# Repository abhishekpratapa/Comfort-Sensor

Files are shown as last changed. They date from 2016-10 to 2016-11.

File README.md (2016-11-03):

# Comfort-Sensor

This is a walk through of designing and manufacturing a microcontroller based project. The goal is to design a consumer product.

My new product is developed from this idea. It is capable of detecting the hygine levels in any environment. Bacteria, Mold, Dust, Hydrocarbon gases. Please email me if you have any questions or are interested in ordering such a product for your family. abhishekpratapa@gmail.com

## Introduction

I've been having a bunch of headaches lately and I didn't know what the cause of those headaches was. Secondarily, during these migraines, I would notice that my mouth felt extremely parched. Initially I had thought that the cause for these symptoms was that I wasn't drinking enough water. This, however, was not the case. I was drinking more than enough of my share of water and I was still feeling horrible. I needed to do something.

I finally arrived on the conclusion that the environment around me was partially causing these symptoms. I decided to build a sensor that told me the humidity and temperature readings in my environment; it would sort of be like a comfort indicator to determine whether these headaches were caused by my surroundings.

## Prototyping

### Planning the User Experience

User Experience is most important when designing a device like this one. What do we want the user to see? Based off of the limited number of components I had available to me I opted for an analog approach in displaying the temperature and the humidity. It would sort of be like a clock. PLEASE spend more time than I did on this. You need to nail this in order to retain customers or users. The User Experience is illustrated below.

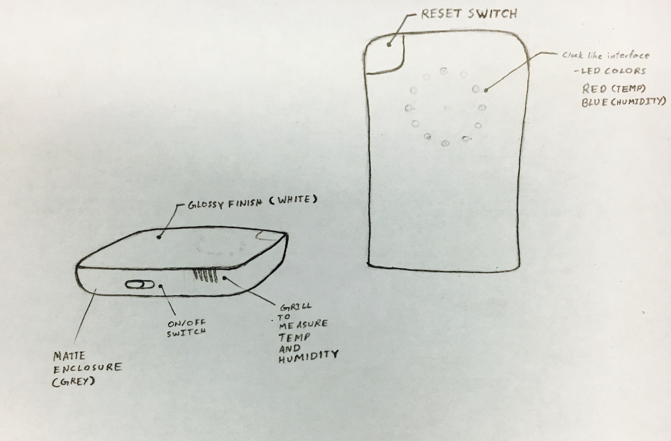
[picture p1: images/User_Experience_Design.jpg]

A Design Prototype

### List of Components

I began rummaging through my electronics and I managed to find a few components that I thought would be ideal to make such a device. They are listed below:

#### Components in the Prototype

- Neo Pixel Ring
- Teensy 3.1
- Battery Management Unit
- Switch
- DHT22 Humidity and Temperature Sensor
- LiPo Battery

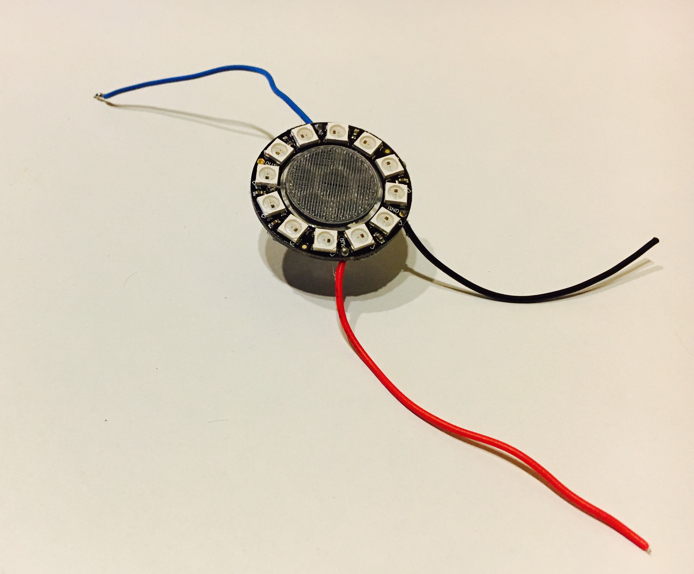
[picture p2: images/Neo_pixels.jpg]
Neo Pixels

Neo Pixel Ring

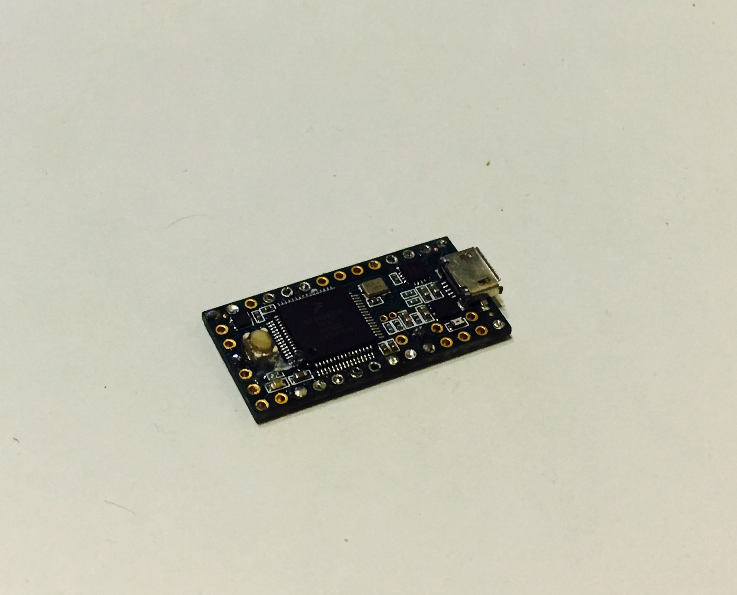
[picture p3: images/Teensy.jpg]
Teensy 3.1

Teensy 3.1

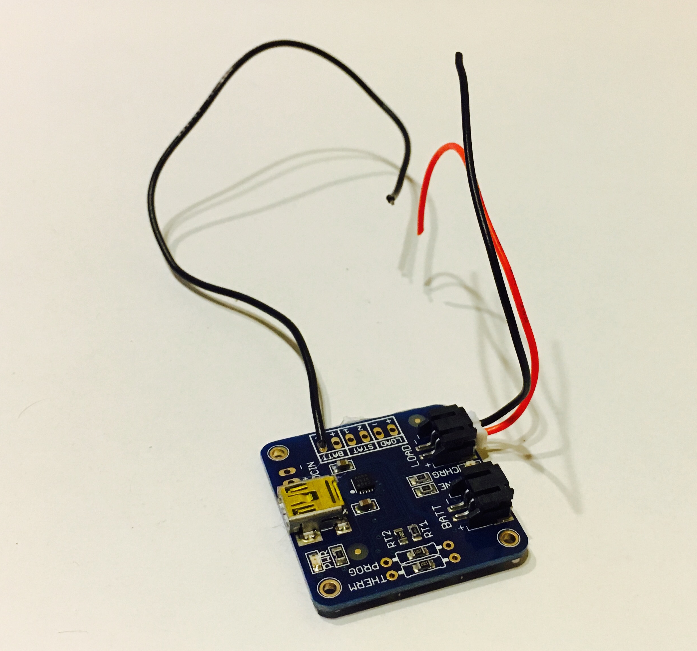
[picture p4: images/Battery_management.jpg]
Battery Management Unit

Battery Management Unit

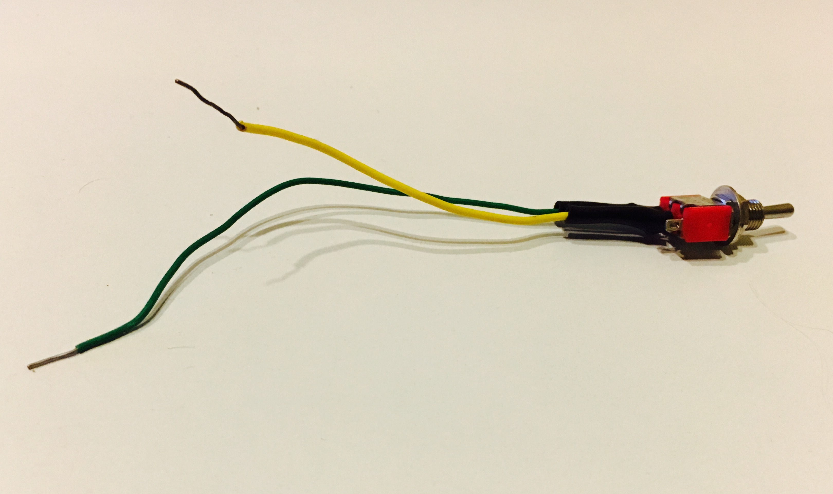
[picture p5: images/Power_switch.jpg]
Power Switch

Switch

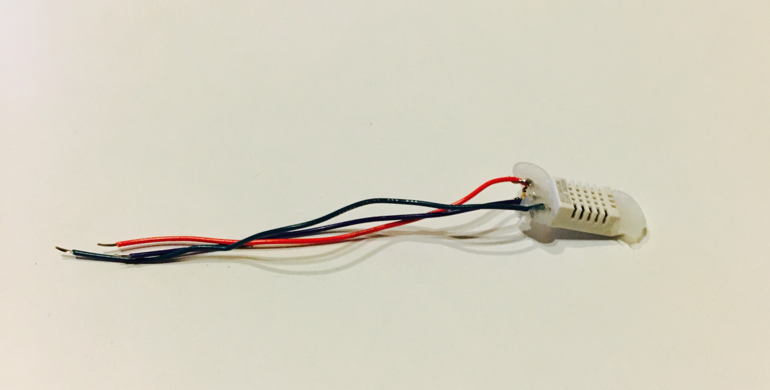
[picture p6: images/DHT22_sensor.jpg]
DHT22 Humidity and Temperature Sensor

DHT22 Humidity and Temperature Sensor

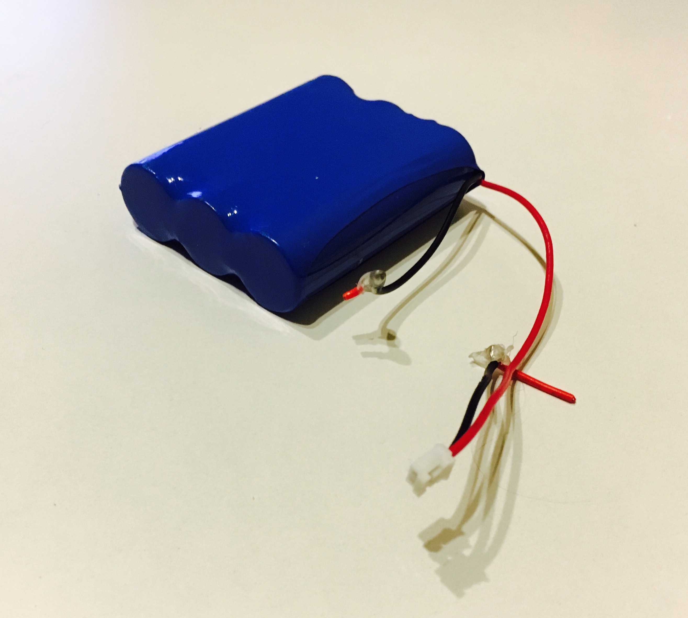
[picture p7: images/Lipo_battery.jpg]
Battery

LiPo Battery

#### Tools used to build the Prototype

- Flush Cutters
- Soldering Iron

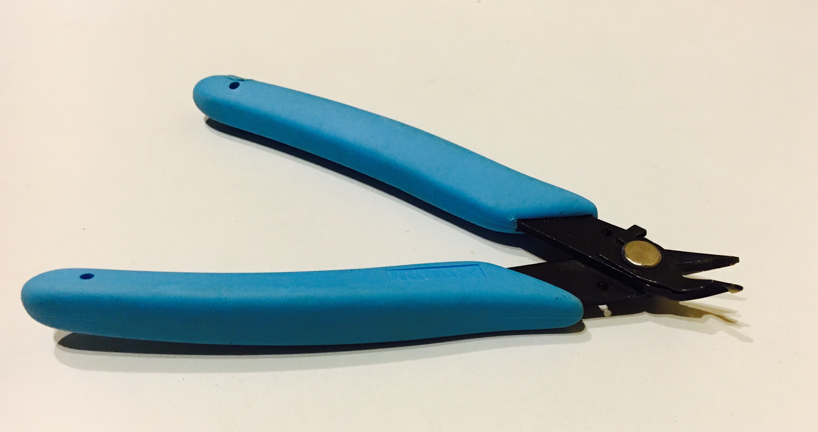
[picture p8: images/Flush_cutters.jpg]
Flush Cutters

Flush Cutters

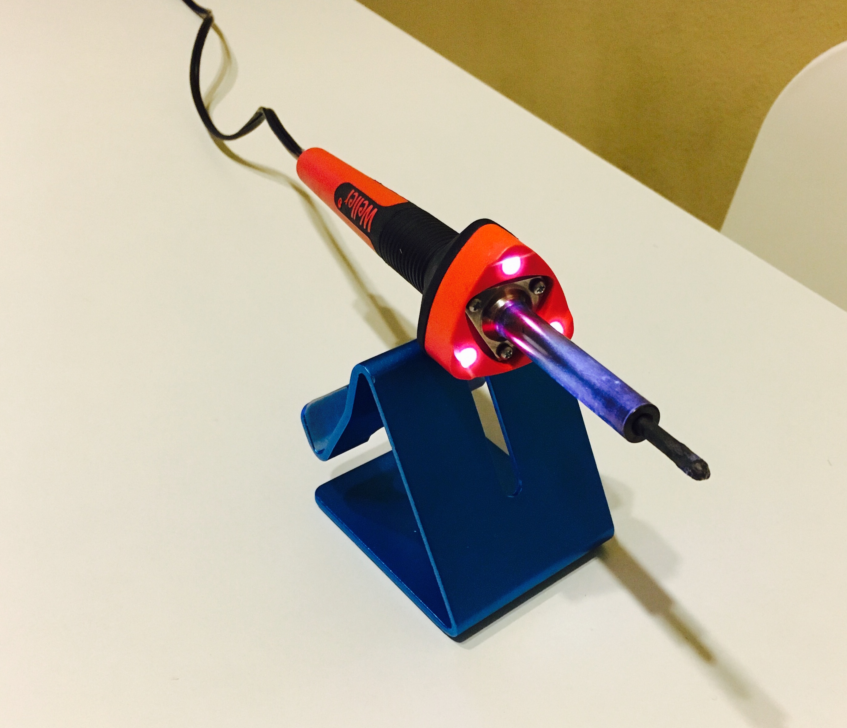
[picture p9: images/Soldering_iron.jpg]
Soldering Iron

Soldering Iron

### Planing the wiring Diagram

Below is a figure of the wiring diagram I created. It is fairly simple.

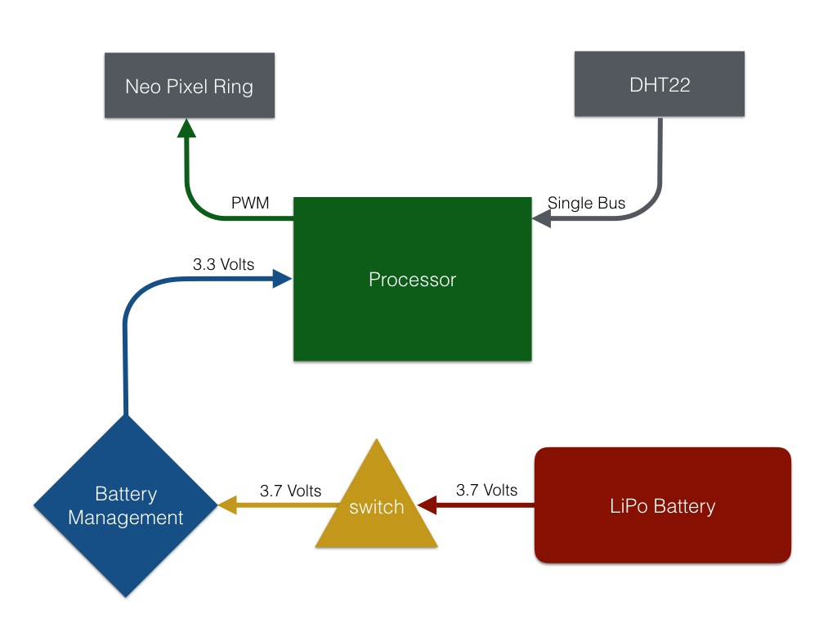
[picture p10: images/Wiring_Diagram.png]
Wiring Diagram

Wiring Diagram

### Wiring up the Prototype

I ended up wiring the device up before I tested it, I had run out of breadboards, and generally this is a horrible idea; however, this was not my first rodeo. I felt confident that I knew what I was doing. Everything worked out without any hiccups.

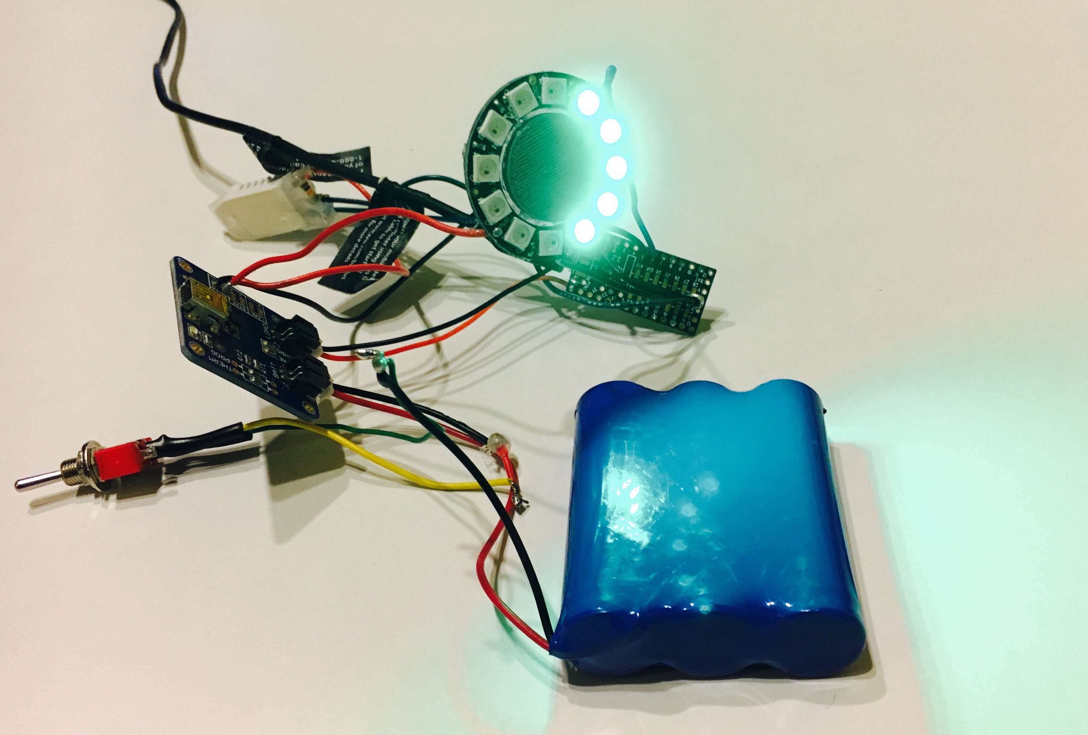
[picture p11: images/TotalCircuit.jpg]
Prototype Switch

Prototype Circuit

### Writing the software

The code design is shown below in the diagram.

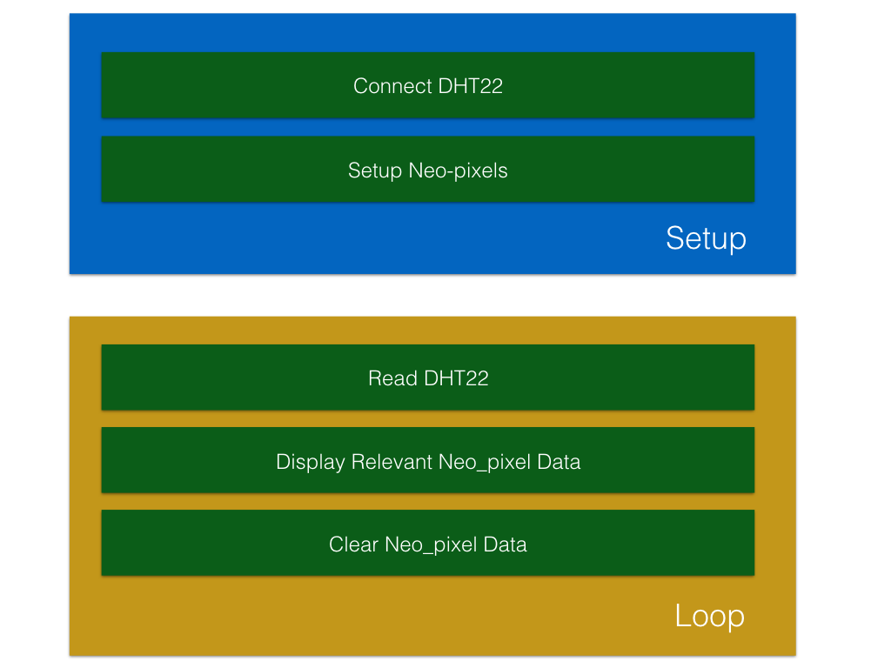
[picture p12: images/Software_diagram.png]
Method Break Down


### Method Break Down

Translating the design to code was a fairly straight forward process. Keeping things simple in Embedded systems design means that space on the micro controller is preserved and that everything is running efficiently. 

#### Setup Method
```
/*
 * Method:  setup
 * 
 * Action:  This method is the setup loop of the program, it sets up the
 *          DHT22 and the Neopixel objects
 * 
 * params:  [None]
 *          
 * return:  void
 * 
 */
```

#### Loop Method

```
/*
 * Method:  loop
 * 
 * Action:  This method is the main loop of the program, it structurally 
 *          calls the other methods to make the program cohesive
 * 
 * params:  [None]
 *          
 * return:  void
 * 
 */
```

#### Display_correct Method

```
/*
 * Method:  display_correct
 * 
 * Action:  This method takes in two parameters, displays the correct 
 *          number of Neo_pixels and the correct color for those pixels
 * 
 * params:  value       Integer value to be displayed in the neo_pixels
 *          sent_color: Enum type color, determines the color to be displayed 
 *                      on the neo_pixels
 *          
 * return:  void
 * 
 */
```

#### Clear_previous Method

```
/*
 * Method:  clear_previous
 * 
 * Action:  This method clears the Neo_pixels and sets the values of all the Neo_pixels to zero
 * 
 * params:  [None]
 * 
 * return:  void
 * 
 */
```

#### Read_sensors Method

```
/*
 * Method:  read_sensors
 * 
 * Action:  This method reads the DHT22 and places the proper data in an int pointer array
 * 
 * params:  *data_retrieved:  This is an Integer array pointer that stores the ones, and tens 
 *                            decimal places for the temperature and the humidity values.
 *                            The first two indexes are the humidity reading and the second two 
 *                            indexes are the temperature reading in [tens, ones] format.
 * 
 * return:  void
 * 
 */
```

### Finalizing 

Here is a video of the prototype of the device

[IMAGE ALT TEXT]
(http://www.youtube.com/watch?v=CA7ydEnhpj4 "Prototype Video")

## PCB Design

Here is the Schematic Design for the project. (Click on it to go to the PDF of the schematic)

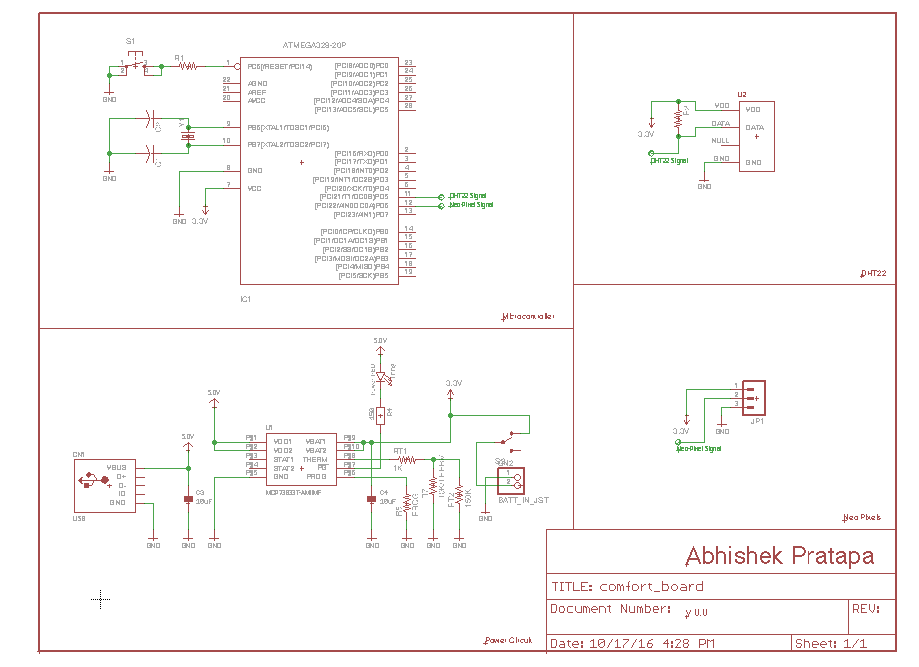
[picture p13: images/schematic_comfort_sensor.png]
IMAGE ALT TEXT
[]
(https://github.com/abhishekpratapa/Comfort-Sensor/blob/master/Comfort_Sensor_PCB/comfort_board.pdf "PDF Schematic")

Here is the PCB design for the project.

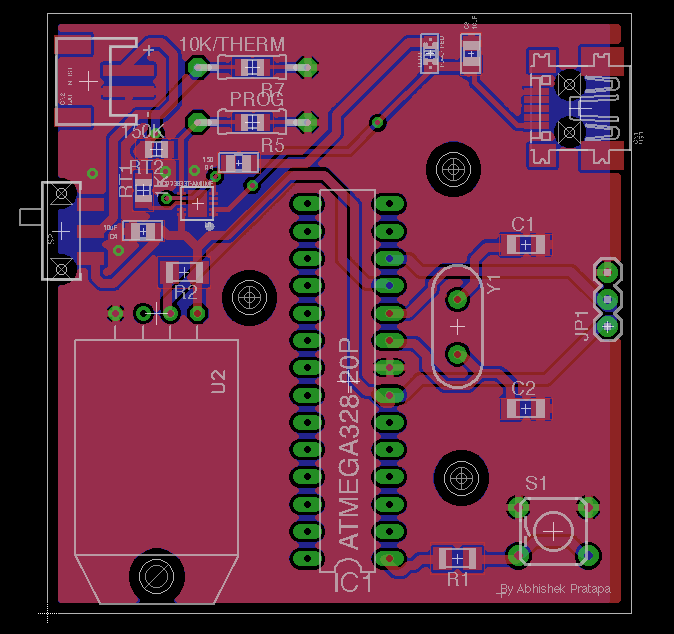
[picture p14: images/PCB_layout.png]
PCB Layout


Please take a look at the eagle CAD and schematic designs in: https://github.com/abhishekpratapa/Comfort-Sensor/tree/master/Comfort_Sensor_PCB

Here is a rendering of the Circuit in Solidworks
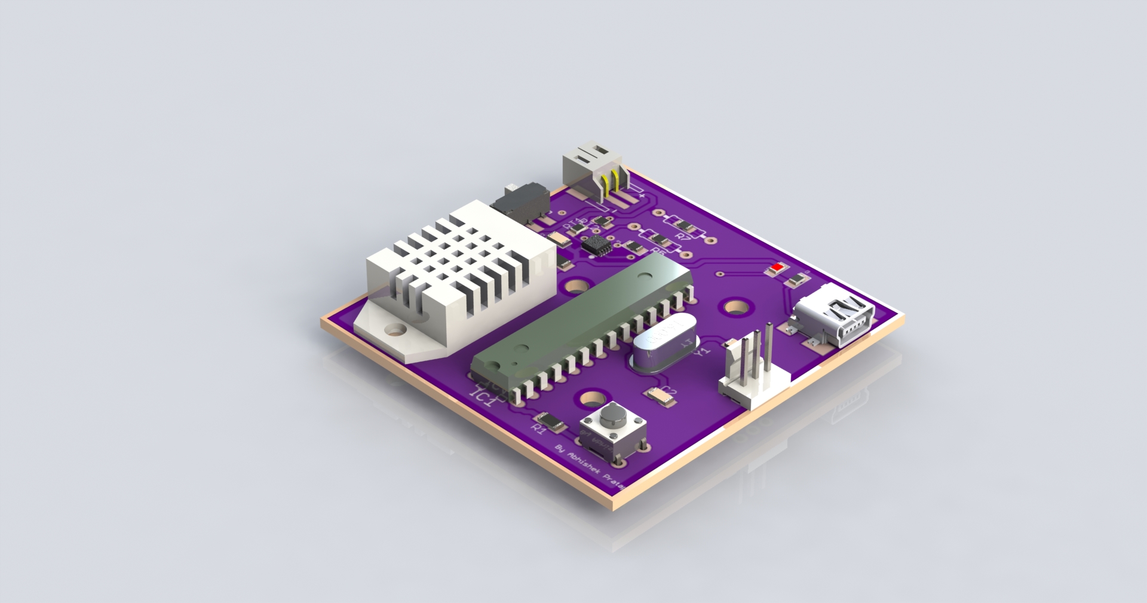
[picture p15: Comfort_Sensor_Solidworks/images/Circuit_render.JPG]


## Financing

### Low Volume

#### Components

| Name of Component | Quantity | Supplier | Price | Shipping | URL |
| :--- | :---: | :---: | :---: | :---: | :--- |
| ATMega328  | 1 | Mouser | $3.70 | $4.70 | http://www.mouser.com/ProductDetail/Atmel/ATMEGA328P-PU/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 |
| Crystal 16MHz | 1 | Mouser | $0.36 | $-.--  | http://www.mouser.com/ProductDetail/CTS/ATS16B-E/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 |
| DHT22  | 1 | Ebay | $3.70 | $-.-- | http://www.ebay.com/itm/New-DHT22-AM2302-Digital-Temperature-Humidity-Sensor-Replace-SHT11-SHT15-Arduino/162147611172 |
| Mini-Pushbutton | 1 | Sparkfun | $0.35 | $2.35  | https://www.sparkfun.com/products/97 |
| Neo-Pixel Ring | 1 | Adafruit | $7.50 | $4.75  | https://www.adafruit.com/products/1643?gclid=CMuP2r6R5c8CFYE2aQodMi0GSg |
| USB Mini B | 1 | Mouser | $0.76 | $1.25  | http://www.mouser.com/ProductDetail/CUI/UJ2-MBH-1-SMT/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 |
| LiPo 3.7V battery pack | 1 | Mouser | $13.68 | $4.25  | http://www.mouser.com/ProductDetail/Renata/ICP402025PC-1/?qs=WtvvTbtNXq%252bQv7inF4n3oA%3d%3d |
| JST-Connector | 1 | Mouser | $0.95 | $-.--  | https://www.sparkfun.com/products/9749 |
| 0805 LED | 1 | DigiKey | $0.50 | $4.58  | http://www.digikey.com/product-detail/en/kingbright/APT2012SECK-J3-PRV/754-1791-1-ND/4753616 |
| Surface Mount Right Angle Switch | 1 | SparkFun | $0.48 |  $-.--  | https://www.sparkfun.com/products/10860 |
| Battery Management Chip | 1 | Mouser | $0.94 |  $-.--  | http://www.mouser.com/ProductDetail/Microchip-Technology/MCP73833T-AMI-MF/?qs=Fxu3fLyJv8epbqy6GsGQQA%3D%3D |
| JST 3-pin  | 1 | SparkFun | $1.50 |  $-.--  | https://www.sparkfun.com/products/9915 |
| 10K Resistor 1206 | 2 | Mouser | $0.19 |  $-.--  | http://www.mouser.com/ProductDetail/ROHM-Semiconductor/KTR18EZPF1002/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 |
| 150 Ohm Resistor 0805 | 1 | Mouser | $0.10 |  $-.--  | http://www.mouser.com/ProductDetail/ROHM-Semiconductor/ESR10EZPJ151/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 |
| 1 kOhm Resistor 0805 | 1 | Mouser | $0.15 |  $-.--  | http://www.mouser.com/ProductDetail/ROHM-Semiconductor/ESR10EZPF1001/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 |
| 10 kOhm Resistor 0805 | 2 | Mouser | $0.17 |  $-.--  | http://www.mouser.com/ProductDetail/ROHM-Semiconductor/KTR10EZPF1002/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 |
| 150 kOhm Resistor 0805 | 1 | Mouser | $0.15 |  $-.--  | http://www.mouser.com/ProductDetail/ROHM-Semiconductor/ESR10EZPF1503/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 |
| 22pF Capicator 1206 | 2 | Mouser | $0.10 |  $-.--  | http://www.mouser.com/ProductDetail/Vishay-Vitramon/VJ1206A220JXJCW1BC/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 |
| 10pF Capicator 0805 | 2 | Mouser | $0.10 |  $-.--  | http://www.mouser.com/ProductDetail/AVX/0805YD106KAT2A/?qs=dV90weSEKCml0j81AJ8E6Q%3D%3D |

#### PCB Cost

| Quantity | Supplier | Price | Shipping |
| :--- | :---: | :---: | :---: |
| 3 | Osh Park | $23.50 | $12.50 |
| 40 | Osh Park | $188.00 | $12.50 |

#### Consumables

| Name of Consumable | Quantity | Supplier | Price | Shipping | URL |
| :--- | :--- | :---: | :---: | :---: | :--- |
| Solder Paste | 3 | Digi-Key | $23.50 | $4.89 | http://www.digikey.com/product-detail/en/SMD291AX/SMD291AX-ND/1160002 |

#### Housing Costs

#### Manufacturing Costs

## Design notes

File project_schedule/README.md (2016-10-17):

# Project Schedule

(Note: This is a special 48 hour project build)

Start Time: October 16, 2016 4:30pm
End Time:   October 17, 2016 TBD

##Arduino Code
  - [x] Link up the DHT22 sensor to the code and stream in data                                         (  October 16, 2016  5:13pm  )
  - [x] Link up the Adafruit Neo-pixels to the code and modify the pixels                               (  October 16, 2016  5:17pm  )
  - [x] Modularize both the sensor and neo_pixel code                                                   (  October 16, 2016  8:26pm  )
  - [x] Plan the UX on the device                                                                       (  October 16, 2016  10:26pm )
  - [x] Code the Main Loop to follow the UX pattern                                                     (  October 16, 2016  11:56pm )
  - [x] Comment code                                                                                    (  October 17, 2016  12:31am )

##PCB Design
  - [x] Spec out the relevant components                                                                
  - [ ] Calculate the power requirements on the circuit and validate battery consumption and life      
  - [x] Create and modularize the circuit schematic on Eagle
  - [x] Plan the Board Design for the PCB, and create a price estimate for the board
  - [ ] Create a price list for the PCB

##Hardware Modeling
  - [ ] Model PCB in the 3d program
  - [ ] Model individual components
  - [ ] Model Casing
  - [ ] Route extraneous wires in the casing
  - [ ] Update pricing sheet to the project
  - [ ] Run injection molding tests, and power dissapation tests (OPTIONAL)

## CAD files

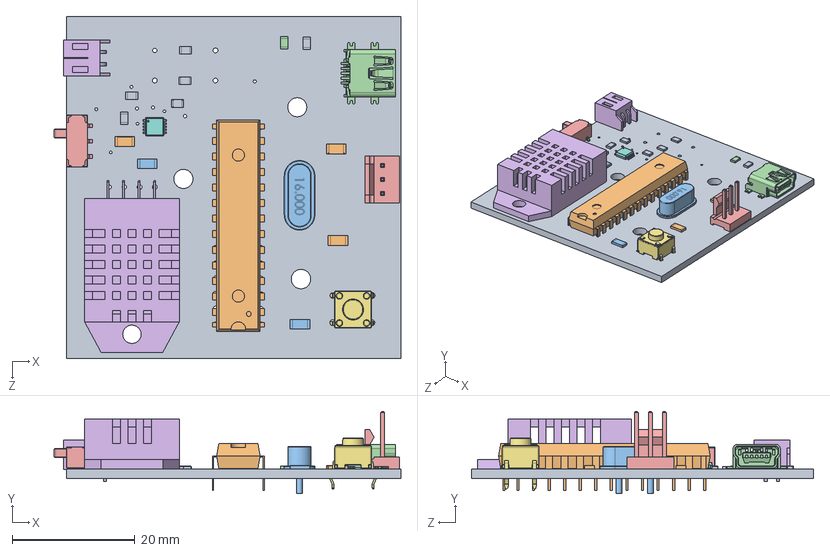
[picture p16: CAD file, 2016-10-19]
Comfort_Sensor_Solidworks/PCB_Assembly.SLDASM
56.6 x 13.4 x 55.9 mm
PCB_Model
ATMega328
crystal
USB_B_mini
SMD_switch
DHT22
tactileswitch
battery_manamagement_unit
RES805 x 6
RES1206 x 3
CAP1206 x 2
LED805
3-Pin Fan Header
connector

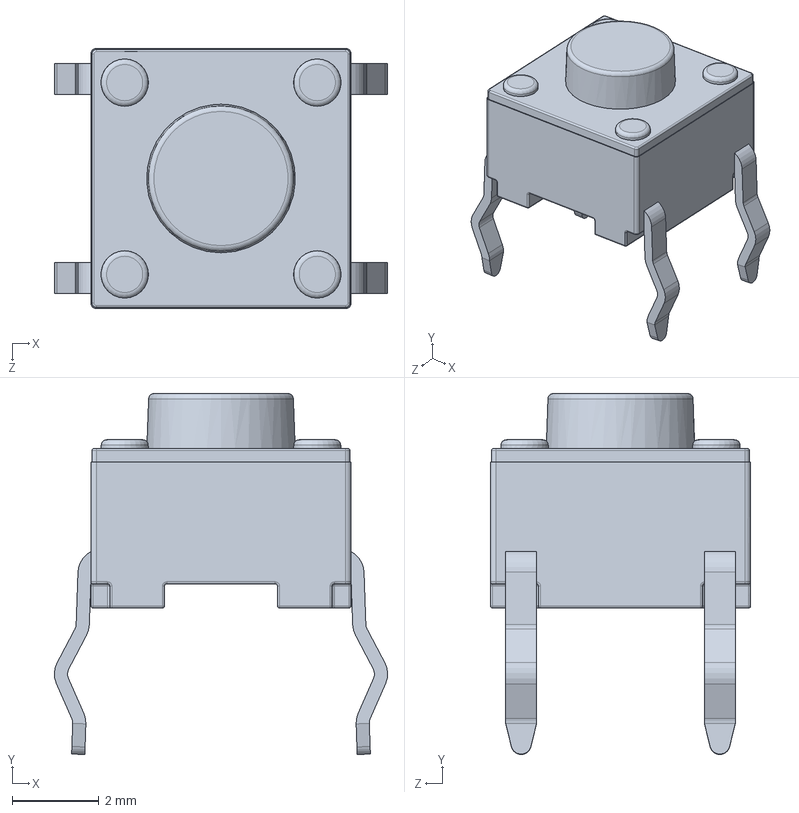
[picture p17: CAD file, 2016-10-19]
Comfort_Sensor_Solidworks/tactileswitch.SLDPRT
7.69 x 8.33 x 6.01 mm

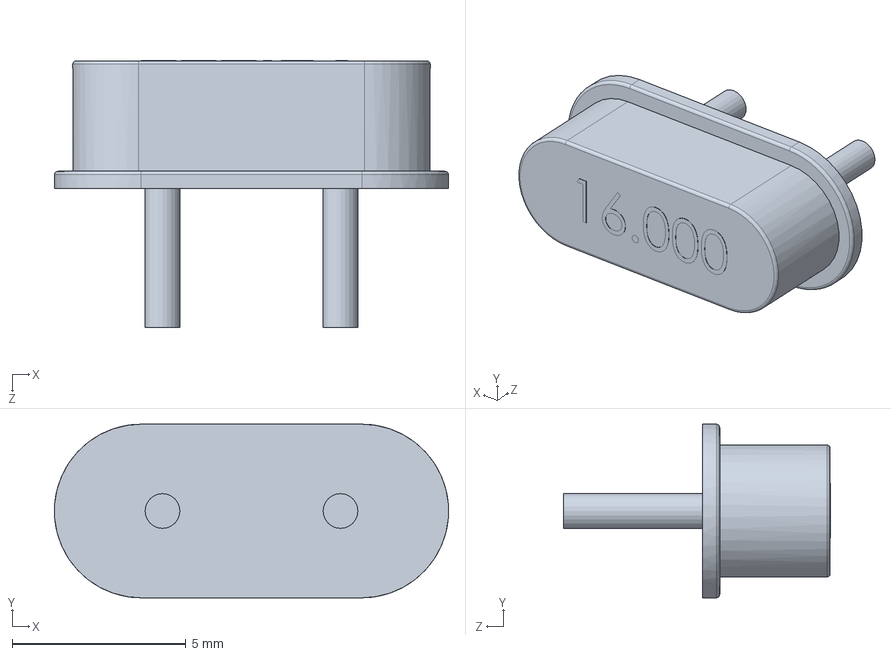
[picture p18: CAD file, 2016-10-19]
Comfort_Sensor_Solidworks/crystal.SLDPRT
11.3 x 5.00 x 7.69 mm

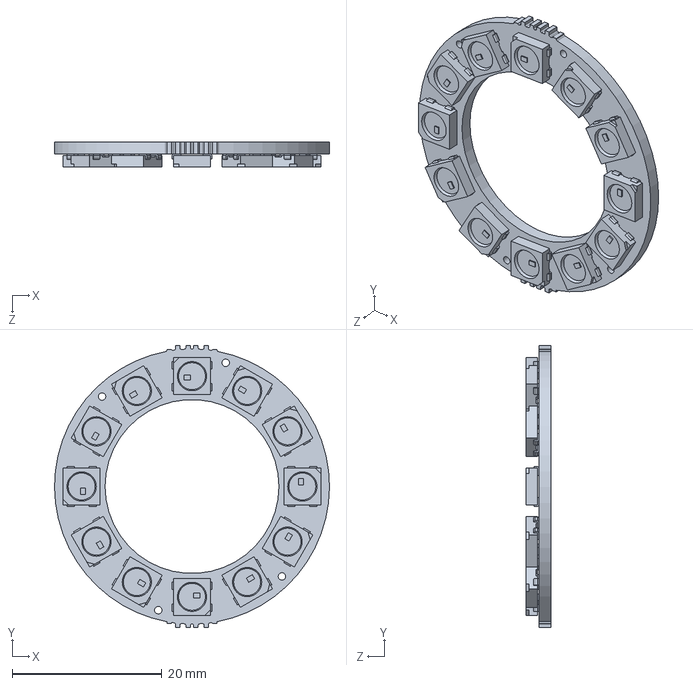
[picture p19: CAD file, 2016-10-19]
Comfort_Sensor_Solidworks/Adafruit neopixel ring.SLDPRT
36.7 x 37.7 x 3.31 mm

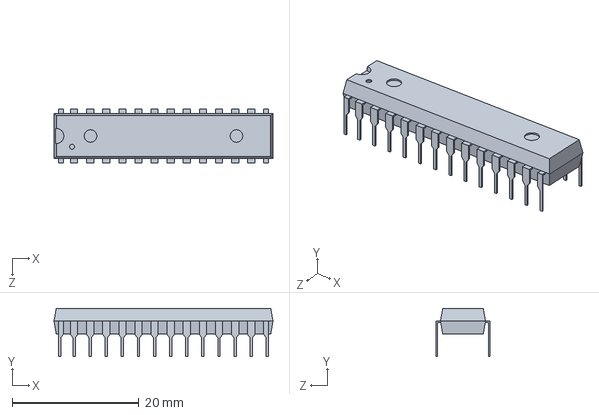
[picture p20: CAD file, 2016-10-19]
Comfort_Sensor_Solidworks/ATMega328.SLDPRT
34.5 x 7.64 x 8.52 mm

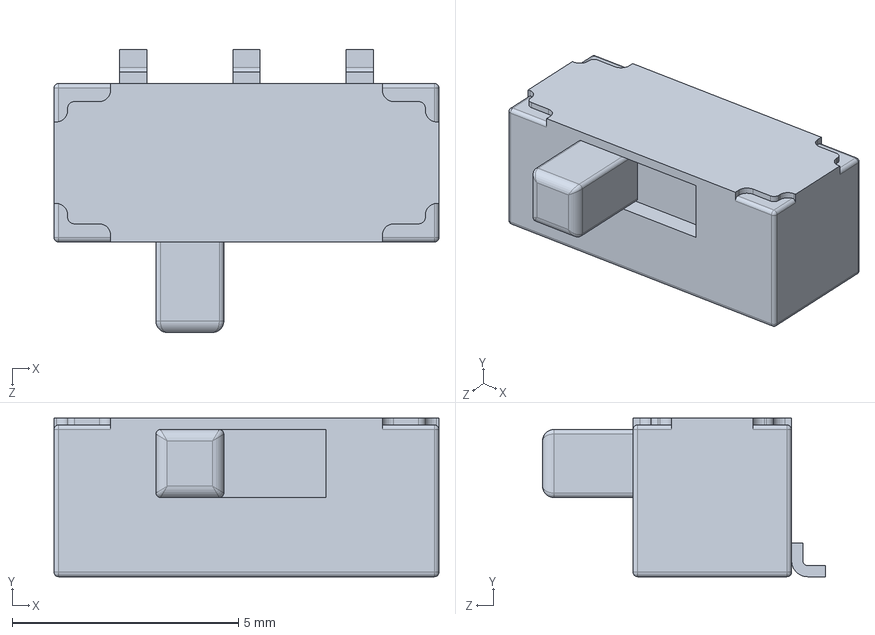
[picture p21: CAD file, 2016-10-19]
Comfort_Sensor_Solidworks/SMD_switch.SLDPRT
8.50 x 3.50 x 6.25 mm

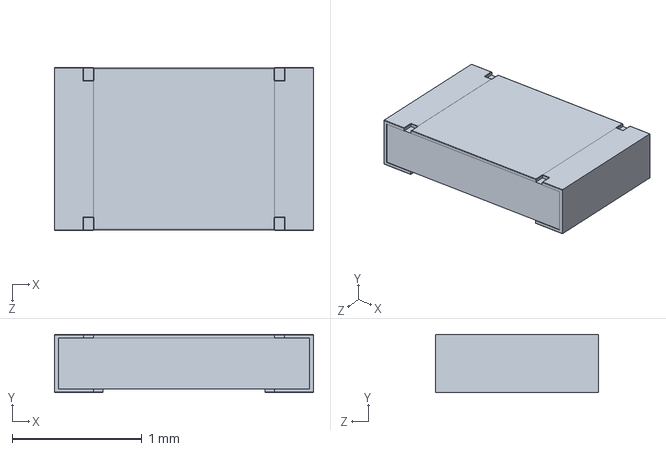
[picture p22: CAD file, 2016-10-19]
Comfort_Sensor_Solidworks/CAP805.SLDPRT
2.00 x 0.45 x 1.26 mm

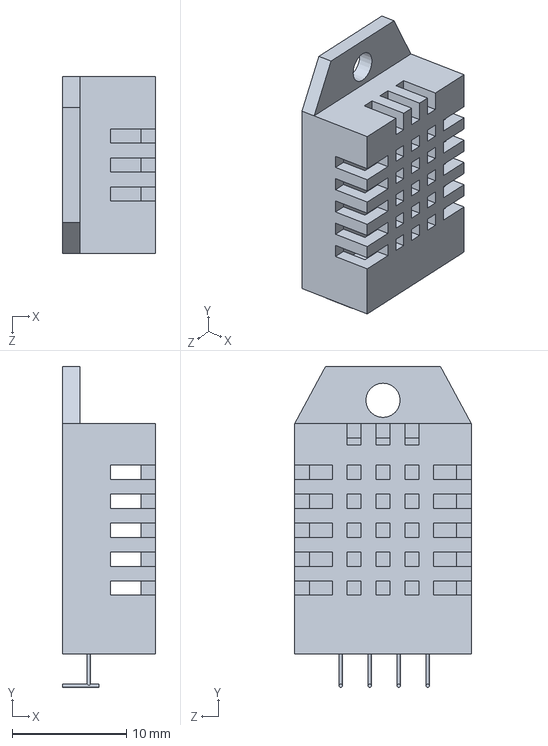
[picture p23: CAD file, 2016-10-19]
Comfort_Sensor_Solidworks/DHT22.SLDPRT
8.15 x 28.1 x 15.5 mm

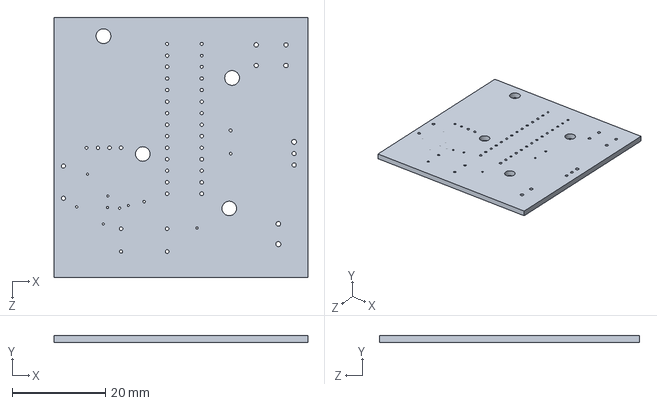
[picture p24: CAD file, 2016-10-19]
Comfort_Sensor_Solidworks/PCB_Model.SLDPRT
54.6 x 1.60 x 55.9 mm

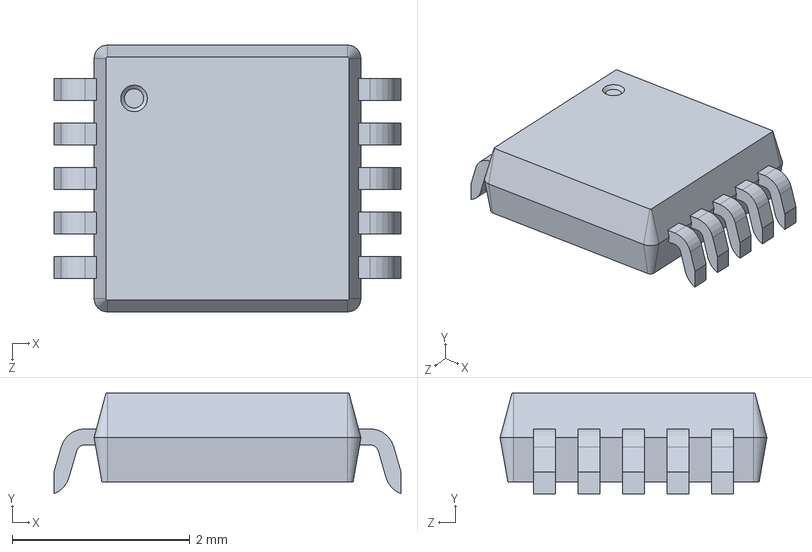
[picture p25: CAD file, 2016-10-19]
Comfort_Sensor_Solidworks/battery_manamagement_unit.SLDPRT
3.90 x 1.13 x 3.00 mm

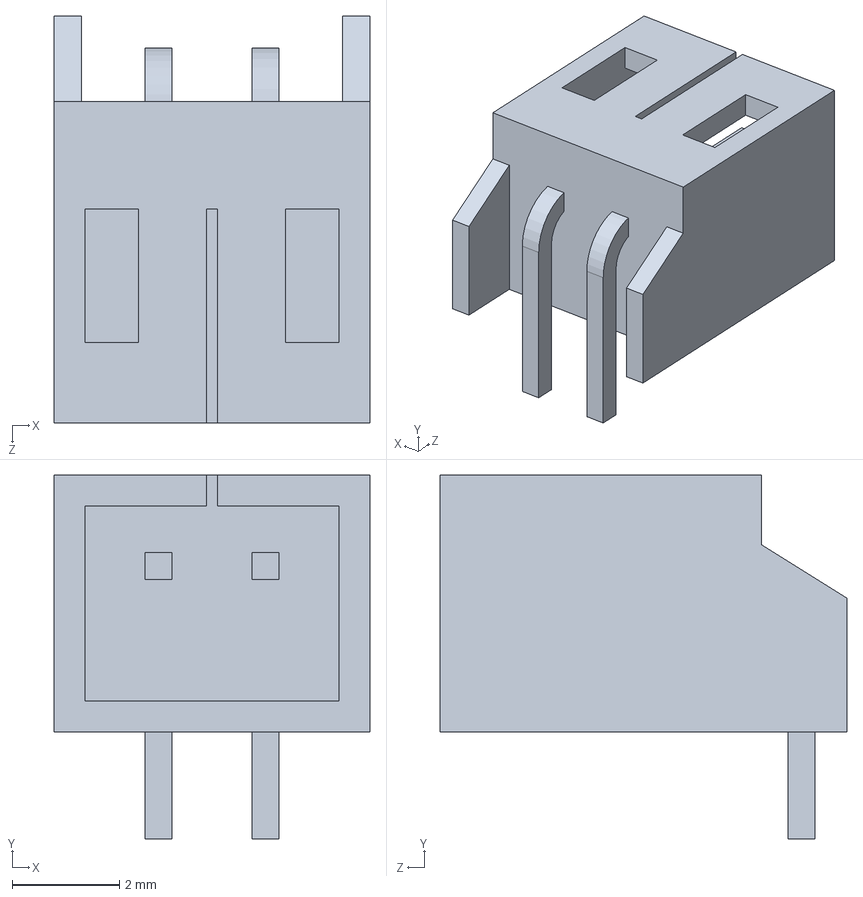
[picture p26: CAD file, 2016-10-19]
Comfort_Sensor_Solidworks/connector.SLDPRT
5.90 x 6.80 x 7.60 mm

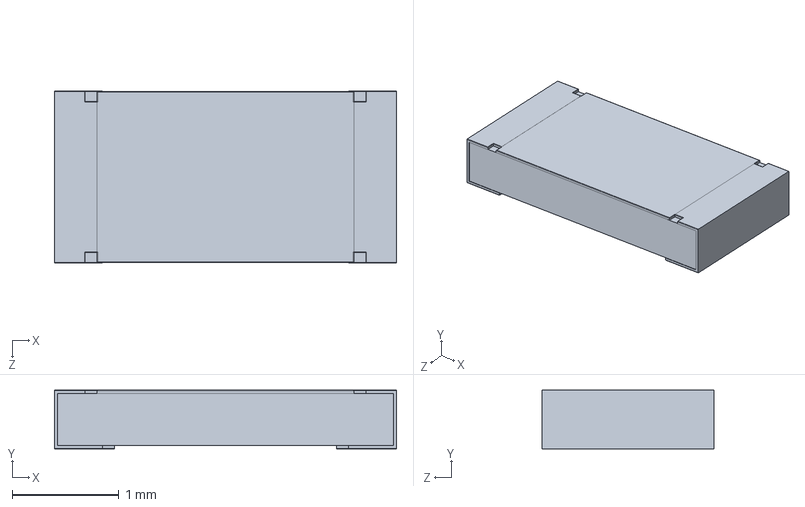
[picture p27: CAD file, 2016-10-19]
Comfort_Sensor_Solidworks/CAP1206.SLDPRT
3.20 x 0.55 x 1.61 mm

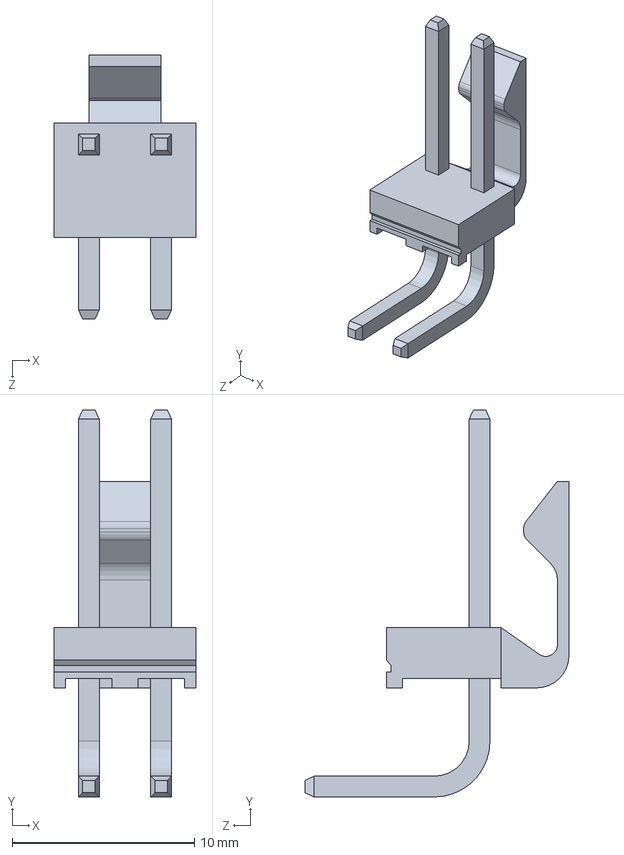
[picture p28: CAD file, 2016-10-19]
Comfort_Sensor_Solidworks/2pin.SLDPRT
7.77 x 21.2 x 14.5 mm

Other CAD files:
Comfort_Sensor_Solidworks/RES805.SLDPRT
Comfort_Sensor_Solidworks/RES1206.SLDPRT
Comfort_Sensor_Solidworks/LED805.SLDPRT

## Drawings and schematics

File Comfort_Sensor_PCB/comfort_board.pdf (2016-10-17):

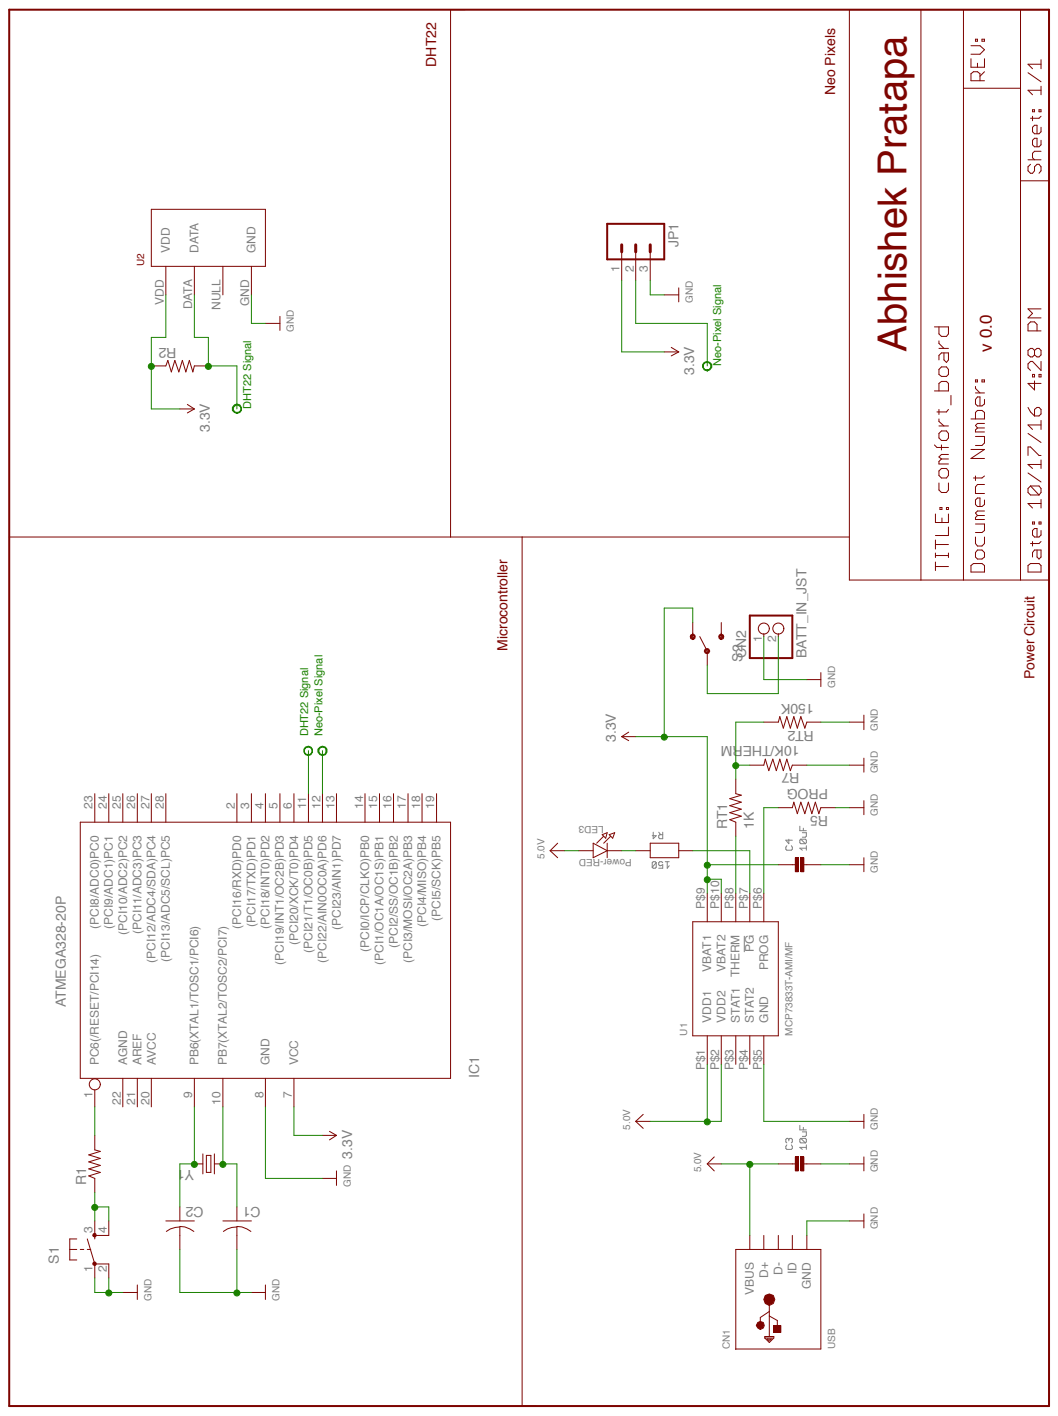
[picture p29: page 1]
ATMEGA328-20P; MCP73833T-AMI/MF; USB; BATT_IN_JST; GND GND; GND; GND 3.3V; (PCI5/SCK)PB5 19; PB7(XTAL2/TOSC2/PCI7) 10; PB6(XTAL1/TOSC1/PCI6) 9; GND 8; VCC 7; AGND 22 AREF 21; AVCC 20; VDD2 P$2; STAT1 P$3; STAT2 P$4 PG P$7; GND P$5 PROG P$6; THERM P$8; VBAT1 P$9 VDD1 P$1; VBAT2 P$10 CN1; VBUS; VDD VDD; DATA DATA; NULL; Microcontroller; DHT22; Neo Pixels; Power Circuit; Abhishek Pratapa; DHT22 Signal

Neo-Pixel Signal

(PCI13/ADC5/SCL)PC5 28 (PCI12/ADC4/SDA)PC4 27 (PCI11/ADC3)PC3 26 (PCI10/ADC2)PC2 25 (PCI9/ADC1)PC1 24 (PCI8/ADC0)PC0 23 PC6(/RESET/PCI14) 1

(PCI23/AIN1)PD7 13 (PCI22/AIN0OC0A)PD6 12 (PCI21/T1/OC0B)PD5 11 (PCI20/XCK/T0)PD4 6 (PCI19/INT1/OC2B)PD3 5 (PCI18/INT0)PD2 4 (PCI17/TXD)PD1 3 (PCI16/RXD)PD0 2

(PCI4/MISO)PB4 18 (PCI3/MOSI/OC2A)PB3 17 (PCI2/SS/OC1B)PB2 16 (PCI1/OC1A/OC1S)PB1 15 (PCI0/ICP/CLKO)PB0 14

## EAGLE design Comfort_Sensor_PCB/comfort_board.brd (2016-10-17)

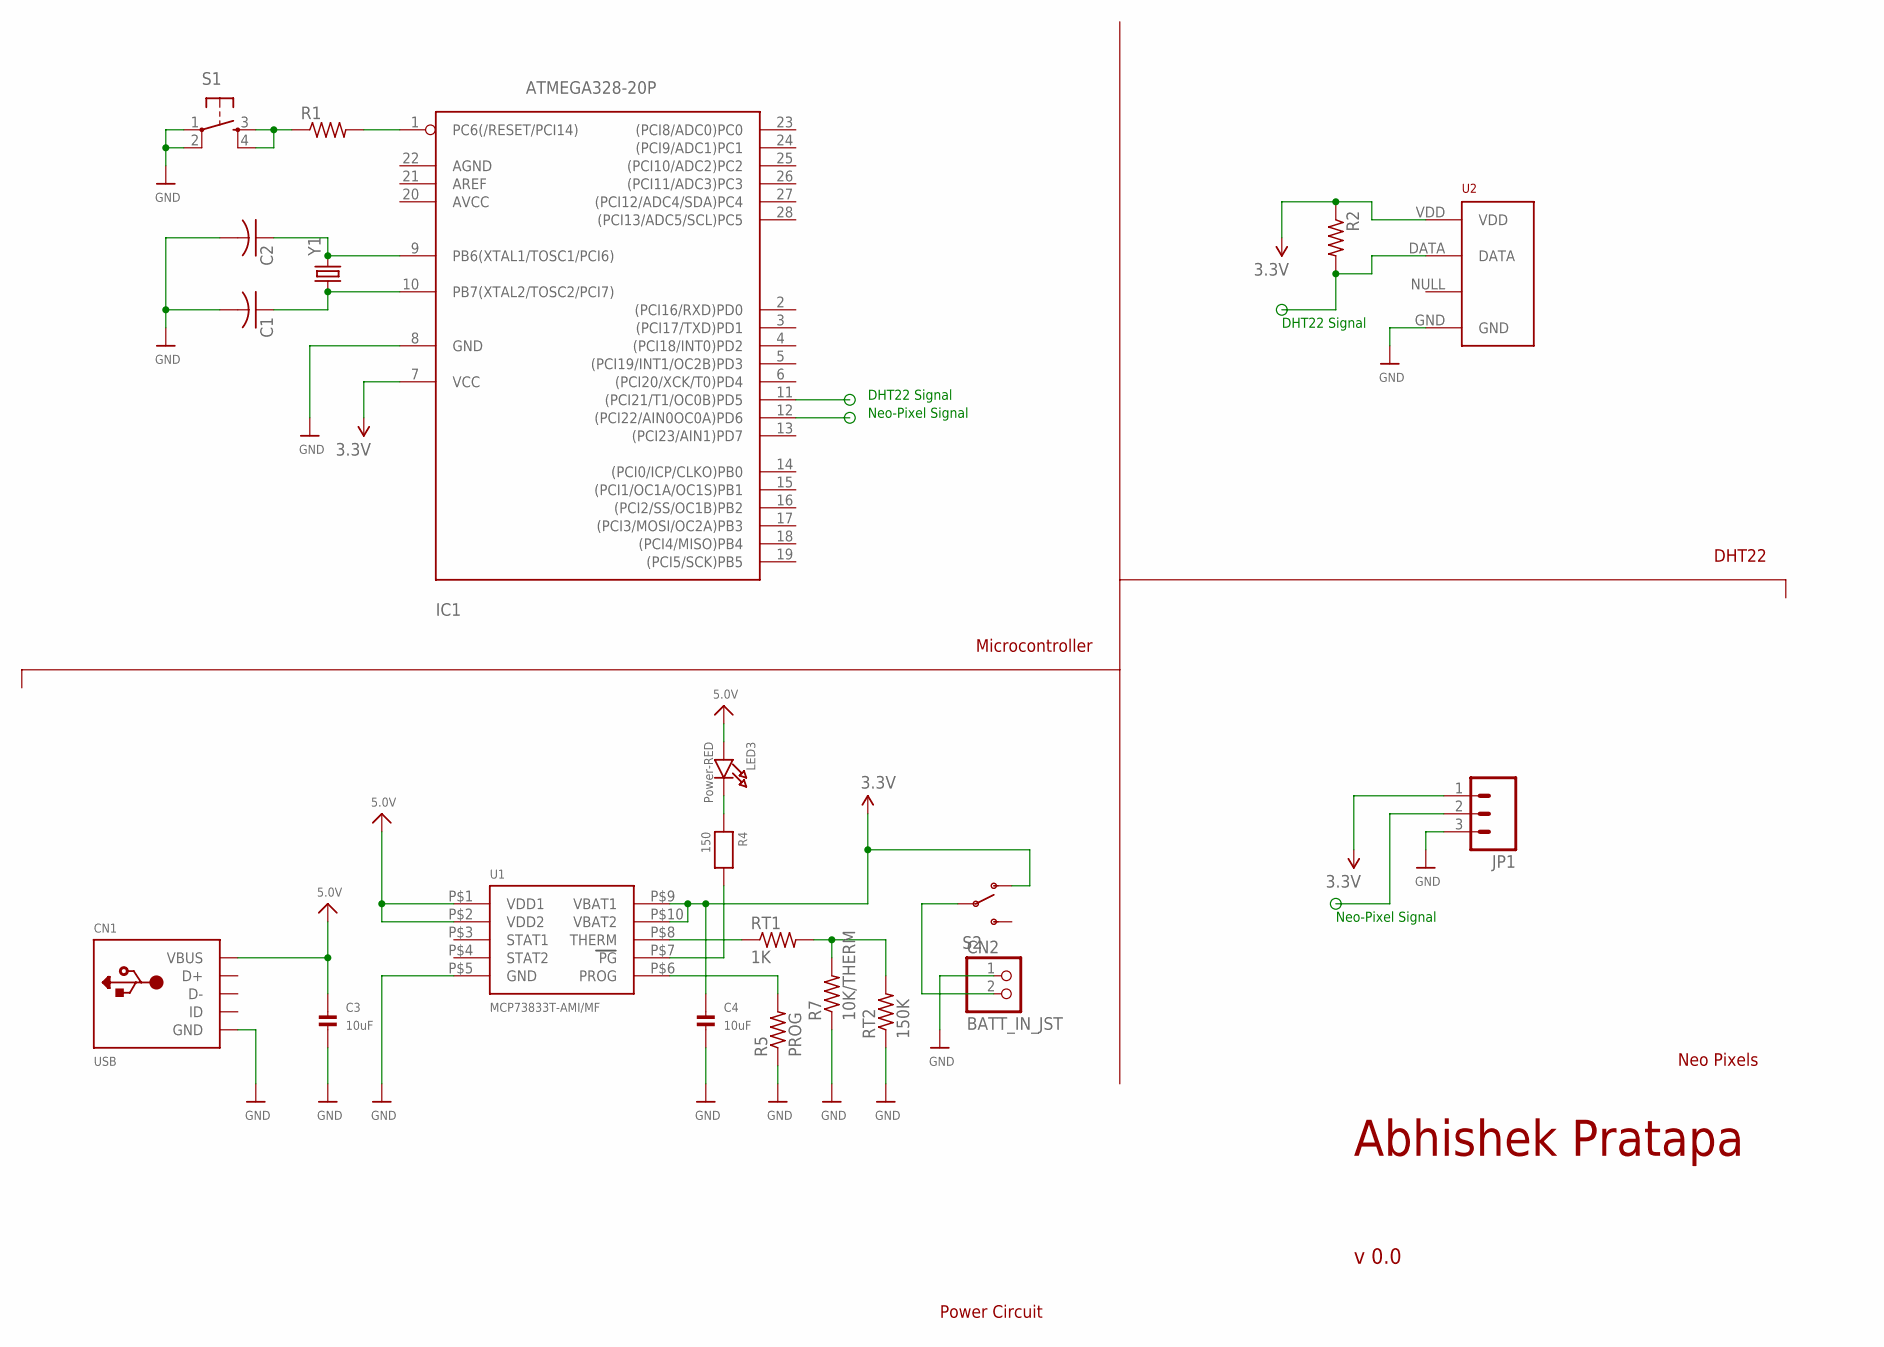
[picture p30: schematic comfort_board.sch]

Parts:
C1, C2: C-USC1206; C1206
C3, C4: 10uF; 0805
CN1: USB; USB-MINIB_LARGER
CN2: BATT_IN_JST; JSTPH2
IC1: ATMEGA328-20P; DIL28-3
JP1: M03PTH; 1X03
LED3: Power-RED; CHIPLED_0805
R1, R2: R-US_M1206; M1206
R4: 150; 0805
R5: PROG; 0805-THM
R7: 10K/THERM; 0805-THM
RT1: 1K; R0805
RT2: 150K; R0805
S1: TAC_SWITCHPTH; TACTILE-PTH
S2: SWITCH-SPSTSMD2; SWITCH-SPDT-SMD
U1: MCP73833T-AMI/MF; DFN10_3X3MM
U2: RHT03_DHT-22_AM2302RA; RHT03_DHT-22/RA
Y1: CRYSTALHC49US; HC49US

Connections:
3.3V: C4.1, IC1.7 (VCC), JP1.1, R2.1, S2.1 (O), U1.P$9 (VBAT1), U1.P$10 (VBAT2), U2.VDD
5.0V: C3.1, CN1.VBUS, LED3.A, U1.P$1 (VDD1), U1.P$2 (VDD2)
DHT22: IC1.11 ((PCI21/T1/OC0B)PD5), R2.2, U2.DATA
GND: C1.2, C2.2, C3.2, C4.2, CN1.GND, CN2.1, IC1.8 (GND), JP1.3, R5.1, R7.1, RT2.1, S1.1, S1.2, U1.P$5 (GND), U2.GND
unnamed: C2.1, IC1.9 (PB6(XTAL1/TOSC1/PCI6)), Y1.2
unnamed: C1.1, IC1.10 (PB7(XTAL2/TOSC2/PCI7)), Y1.1
unnamed: R1.1, S1.3, S1.4
unnamed: IC1.1 (PC6(/RESET/PCI14)), R1.2
unnamed: IC1.12 ((PCI22/AIN0OC0A)PD6), JP1.2
unnamed: CN2.2, S2.2
unnamed: R4.2, U1.P$7 (PG)
unnamed: RT1.1, U1.P$8 (THERM)
unnamed: R7.2, RT1.2, RT2.2
unnamed: LED3.C, R4.1
unnamed: R5.2, U1.P$6 (PROG)

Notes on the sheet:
DHT22 Signal
Neo-Pixel Signal
Microcontroller
DHT22
Neo Pixels
Power Circuit
Abhishek Pratapa
v 0.0

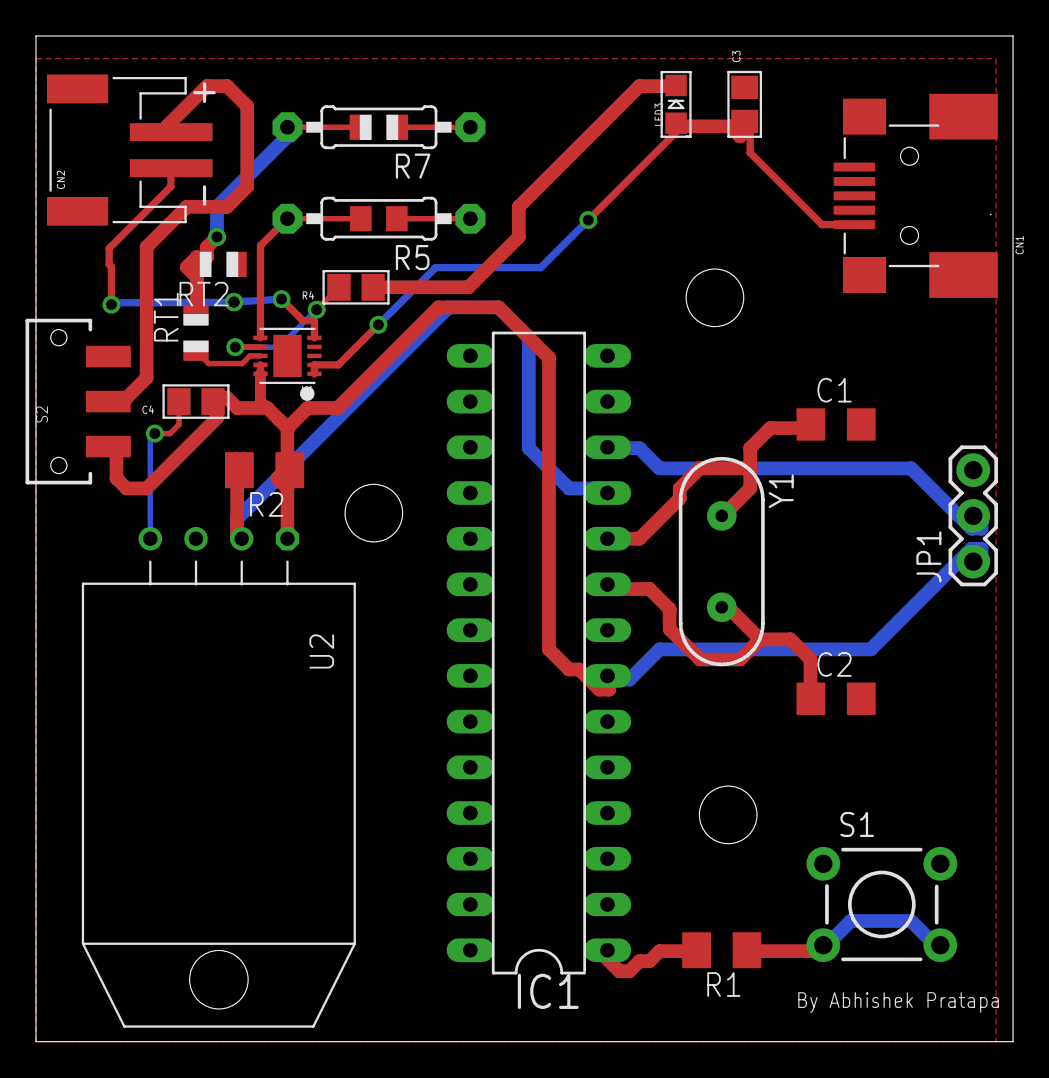
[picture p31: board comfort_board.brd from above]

Board: 2 copper layers, 54.3 x 55.9 mm, 21 parts (0 on the bottom side), 15 nets.

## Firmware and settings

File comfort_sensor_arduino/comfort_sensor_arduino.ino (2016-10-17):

/*
 * Dependencies
 * 
 * Libraries:
 * 
 *      Name                    Author
 *      ________________________________
 *      Adafruit_NeoPixel       Adafruit
 *      DHTSensor               Adafruit
 */
#include "DHT.h"
#include <Adafruit_NeoPixel.h>

// definition for if an ATTiny is used
#ifdef __AVR__
  #include <avr/power.h>
#endif

// definition for the Neo_pixels
#define PIN            6
#define NUMPIXELS      12

// definition for the humidity and temperature sensor
#define DHTTYPE DHT22
#define DHTPIN 5

// set up an object for the neo_pixels
Adafruit_NeoPixel pixels = Adafruit_NeoPixel(NUMPIXELS, PIN, NEO_GRB + NEO_KHZ800);

// set up an object for the temperature and humidity sensor
DHT dht(DHTPIN, DHTTYPE);

// color enumerated values
enum color {
  red,
  green,
  blue
};

// color values for both the humidity reading and the temperature readings
color humidity_color = blue;
color temp_color = red;

// store the ones and tens digits of both the humidity and temperature readings respectively
int sensor_data[4];

/*
 * Method:  setup
 * 
 * Action:  This method is the setup loop of the program, it sets up the
 *          DHT22 and the Neopixel objects
 * 
 * params:  [None]
 *          
 * return:  void
 * 
 */
void setup() {
  
  // definition for an ATTiny
  #if defined (__AVR_ATtiny85__)
    if (F_CPU == 16000000) clock_prescale_set(clock_div_1);
  #endif

  // start the objects
  dht.begin();
  pixels.begin();
}

/*
 * Method:  loop
 * 
 * Action:  This method is the main loop of the program, it structurally 
 *          calls the other methods to make the program cohesive
 * 
 * params:  [None]
 *          
 * return:  void
 * 
 */
void loop() {
  read_sensors(&sensor_data[0]);

  for(int c=0; c<4; c++){
    display_correct(sensor_data[c], (((int)(c/2)) == 0)? humidity_color:temp_color);
    clear_previous();
  }
}

/*
 * Method:  display_correct
 * 
 * Action:  This method takes in two parameters, displays the correct 
 *          number of Neo_pixels and the correct color for those pixels
 * 
 * params:  value       Integer value to be displayed in the neo_pixels
 *          sent_color: Enum type color, determines the color to be displayed 
 *                      on the neo_pixels
 *          
 * return:  void
 * 
 */
void display_correct(int value, color sent_color){
  for(int x=0;x<150;x++){
    for(int i=0;i<NUMPIXELS;i++){
      if(i < value){
        pixels.setPixelColor(i, pixels.Color(((sent_color == red)?x:0),((sent_color == green)?x:0),((sent_color == blue)?x:0)));
      }else{
        pixels.setPixelColor(i, pixels.Color(0,0,0));
      }
    }
    pixels.show();
    delay(10);
  }
}

/*
 * Method:  clear_previous
 * 
 * Action:  This method clears the Neo_pixels and sets the values of all the Neo_pixels to zero
 * 
 * params:  [None]
 * 
 * return:  void
 * 
 */

void clear_previous(){
  for(int i=0;i<NUMPIXELS;i++){
    pixels.setPixelColor(i, pixels.Color(0,0,0));
  }
    
  pixels.show();
  delay(200); 
}

/*
 * Method:  read_sensors
 * 
 * Action:  This method reads the DHT22 and places the proper data in an int pointer array
 * 
 * params:  *data_retrieved:  This is an Integer array pointer that stores the ones, and tens 
 *                            decimal places for the temperature and the humidity values.
 *                            The first two indexes are the humidity reading and the second two 
 *                            indexes are the temperature reading in [tens, ones] format.
 * 
 * return:  void
 * 
 */

void read_sensors(int *data_retrieved){
  
  float h = dht.readHumidity();
  float f = dht.readTemperature(true);
  
  data_retrieved[0] = (int)(h/10.0);
  data_retrieved[1] = (((int)(h))%10);
  data_retrieved[2] = (int)(f/10.0);
  data_retrieved[3] = (((int)(f))%10);
  
}

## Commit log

2016-10-17 Arduino Sensor code
2016-10-17 Linked up DHT sensor to the Arduino code
2016-10-17 updated arduino code
2016-10-17 Added a youtube video of the device
2016-10-17 fixed a documentation error in the code
    [comfort_sensor_arduino.ino]
2016-10-17 many PCB designs
    [comfort_board.brd, comfort_board.sch]
2016-10-18 Eagle cad
2016-10-18 Added more components for the PCB
2016-10-18 Added all parts to the sensor
2016-10-19 added solidworks file
    [2pin.SLDPRT, ATMega328.SLDPRT, Adafruit neopixel ring.SLDPRT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]

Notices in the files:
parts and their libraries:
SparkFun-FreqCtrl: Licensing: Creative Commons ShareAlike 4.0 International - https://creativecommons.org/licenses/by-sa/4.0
